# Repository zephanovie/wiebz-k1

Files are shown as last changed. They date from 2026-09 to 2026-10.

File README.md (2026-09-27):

# WIEBZ-K1
The Beginning of a new brand...WIEBZ (Willed Into Existence By Zephan).....its a 60% keyboard with a cool design (i hope)
it uses a raspberry pi pico as the MCU, the switches would be hot swappable. it has a daisy chain of SK6812 mini-e leds that would be both bottom mounted for the per key led and top mounted that would serve as the ambient lights around three corners of the keyboard...and it would be running the qmk firmware. The PCB was designed in KiCad, the case in Fusion 

# Features <br><br>
- Rp2040 controller
- per-key led
- a 60% layout
- under glow lights
- qmk firmware

# BOM

| **Item** | **Qty** | **Price (₦)** | **Price($)** | **Source** |
|---|---|---|---|---|
| PCB | 5 | 48,964.14 | 36.87 (W Shipping) | JLCPCB |
| Raspberry Pi Pico W | 1 | 23,000 | 17.32 | https://hub360.cc/shop/0408-raspberry-pi-pico-w-rp2040-type-c-dual-core-microcontroller-development-board-12216 |
| Kailh Hotswappable MX Sockets | 70 | 8,237 | 6.2 | https://www.aliexpress.com/item/1005012011087592.html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 |
| MX Mechanical Switches | 70 (10*7) | 22,967.57 (W Shipping) | 17.29 | https://www.aliexpress.com/item/1005003206504286.html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 |
| 1N4148 THT Diodes | 100 | 2,207 | 1.66 | https://www.aliexpress.com/item/4001126137167.html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 |
| Stabilizers | 5 | 14,321 | 10.78 | https://www.aliexpress.com/item/4001143514438.html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 |
| SK6812 MINI-E leds | 100 | 5,224 | 3.93 | https://www.aliexpress.com/item/1005007863635868.html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 |
| Transparent PETG | 250g | 25,099 | 18.9 | https://www.aliexpress.com/item/1005012249653635.html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 |
| Matte Black Petg | 1kg | 65,586 | 49.39 | https://www.aliexpress.com/item/1005010748782693.html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 |
| Screws | 0 | 0 | 0 | Self-Covered |
| Heat Inserts | 0 | 0 | 0 | Self-Covered |
| Key Caps | 133 keys  | 19,885 | 14.97 | https://www.aliexpress.com/item/1005009592262575.html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 |
| TOTAL | | 212,523.14 | 140.44 | 

# Images
## Schematics
#### Keyboard Matrix


#### LED Chain


#### MCU


## PCB
#### PCB Design


#### PCB 3D Render



## Case
#### Plate
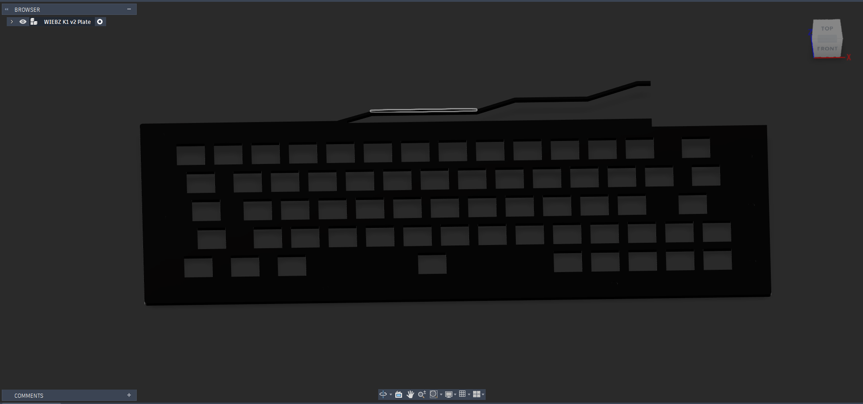
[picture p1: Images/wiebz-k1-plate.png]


#### Base
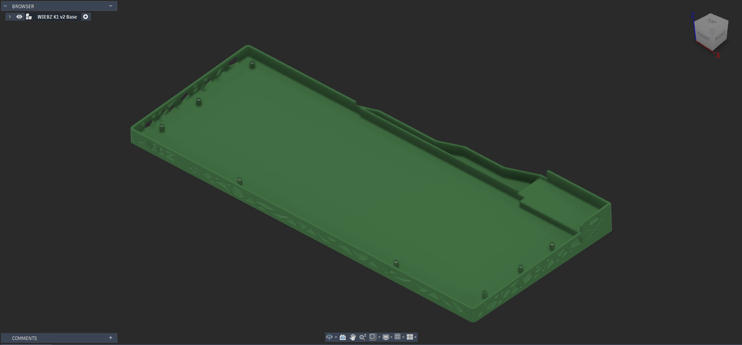
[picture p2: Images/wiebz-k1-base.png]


### MCU Cover
 (to be glue to the plate after printing)
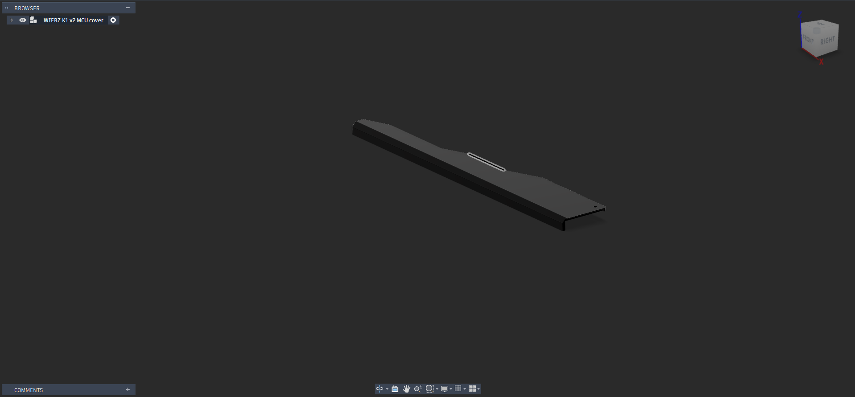
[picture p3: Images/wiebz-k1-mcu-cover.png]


#### Full Case
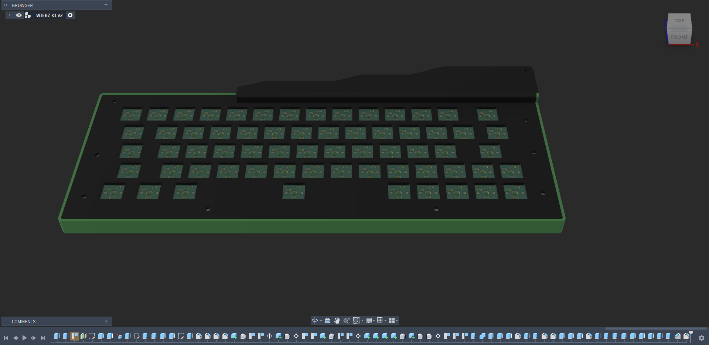
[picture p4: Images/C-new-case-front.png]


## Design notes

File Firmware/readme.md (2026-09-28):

# wiebz_k1

wiebz_k1

*A short description of the keyboard/project*

* Keyboard Maintainer: [Zephan Ovie-Ufuoma](https://github.com/oviezephan)
* Hardware Supported: *The PCBs, controllers supported*
* Hardware Availability: *Links to where you can find this hardware*

Make example for this keyboard (after setting up your build environment):

    make wiebz_k1:default

Flashing example for this keyboard:

    make wiebz_k1:default:flash

See the [build environment setup](https://docs.qmk.fm/#/getting_started_build_tools) and the [make instructions](https://docs.qmk.fm/#/getting_started_make_guide) for more information. Brand new to QMK? Start with our [Complete Newbs Guide](https://docs.qmk.fm/#/newbs).

## Bootloader

Enter the bootloader in 3 ways:

* **Bootmagic reset**: Hold down the key at (0,0) in the matrix (usually the top left key or Escape) and plug in the keyboard
* **Physical reset button**: Briefly press the button on the back of the PCB - some may have pads you must short instead
* **Keycode in layout**: Press the key mapped to `QK_BOOT` if it is available

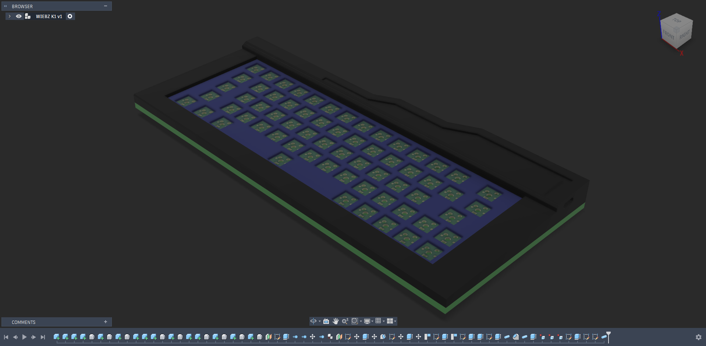
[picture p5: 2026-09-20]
Images/Screenshot 2026-09-20 212914.png

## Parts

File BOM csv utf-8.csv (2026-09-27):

Item | Qty | Price (₦) | Price($) | Source
PCB | 5 | 48,964.14 | 36.87 (W Shipping) | JLCPCB
Raspberry Pi Pico W | 1 | 23,000 | 17.32 | https://hub360.cc/shop/0408-raspberry-pi-pico-w-rp2040-type-c-dual-core-microcontroller-development-board-12216
Kailh Hotswappable MX Sockets | 70 | 8,237 | 6.2 | https://www.aliexpress.com/item/1005012011087592.html?curPageLogUid=ZSE8mI1xv3yo
MX Mechanical Switches | 70 (10*7) | 22,967.57 (W Shipping) | 17.29 | https://www.aliexpress.com/item/1005003206504286.html?curPageLogUid=cNFM0hmjKg5j
1N4148 THT Diodes | 100 | 2,207 | 1.66 | https://www.aliexpress.com/item/4001126137167.html?curPageLogUid=Fgjax7A3c4sT
Stabilizers | 5 | 14,321 | 10.78 | https://www.aliexpress.com/item/4001143514438.html?curPageLogUid=hGLGjyTulFV4
SK6812 MINI-E leds | 100 | 5,224 | 3.93 | https://www.aliexpress.com/item/1005007863635868.html?curPageLogUid=zBx0bm7r2RNj
Transparent PETG | 250g | 25,099 | 18.9 | https://www.aliexpress.com/item/1005012249653635.html?curPageLogUid=4ECKxfp5A1b7
Matte Black Petg | 1kg | 65,586 | 49.39 | https://www.aliexpress.com/item/1005010748782693.html?curPageLogUid=UkhFswVuA9qj
Screws | 0 | 0 | 0 | Self-Covered
Heat Inserts | 0 | 0 | 0 | Self-Covered
Key Caps | 133 keys | 19,885 | 14.97 | https://www.aliexpress.com/item/1005009592262575.html?curPageLogUid=Qs7ffMCvOio6
TOTAL |  | 212,523.14 | 140.44

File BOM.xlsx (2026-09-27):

Item | Qty | Price (₦) | Price($) | Source
PCB | 5 | 48964.14 | 36.87 (W Shipping) | JLCPCB
Raspberry Pi Pico W | 1 | 23000 | 17.32 | https://hub360.cc/shop/0408-raspberry-pi-pico-w-rp2040-type-c-dual-core-microcontroller-development-board-12216
Kailh Hotswappable MX Sockets | 70 | 8237 | 6.2 | https://www.aliexpress.com/item/1005012011087592.html?curPageLogUid=ZSE8mI1xv3yo
MX Mechanical Switches | 70 (10*7) | 22,967.57 (W Shipping) | 17.29 | https://www.aliexpress.com/item/1005003206504286.html?curPageLogUid=cNFM0hmjKg5j
1N4148 THT Diodes | 100 | 2207 | 1.66 | https://www.aliexpress.com/item/4001126137167.html?curPageLogUid=Fgjax7A3c4sT
Stabilizers | 5 | 14321 | 10.78 | https://www.aliexpress.com/item/4001143514438.html?curPageLogUid=hGLGjyTulFV4
SK6812 MINI-E leds | 100 | 5224 | 3.93 | https://www.aliexpress.com/item/1005007863635868.html?curPageLogUid=zBx0bm7r2RNj
Transparent PETG | 250g | 25099 | 18.9 | https://www.aliexpress.com/item/1005012249653635.html?curPageLogUid=4ECKxfp5A1b7
Matte Black Petg | 1kg | 65586 | 49.39 | https://www.aliexpress.com/item/1005010748782693.html?curPageLogUid=UkhFswVuA9qj
Screws | 0 | 0 | 0 | Self-Covered
Heat Inserts | 0 | 0 | 0 | Self-Covered
Key Caps | 133 keys | 19885 | 14.97 | https://www.aliexpress.com/item/1005009592262575.html?curPageLogUid=Qs7ffMCvOio6
TOTAL |  | 212523.14 | 140.44

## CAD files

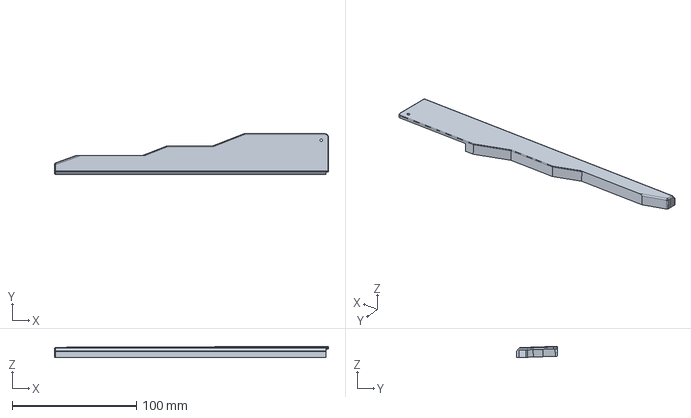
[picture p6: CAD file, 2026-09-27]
Case/WIEBZ K1 v2 MCU cover.step
220.8 x 33.2 x 9.13 mm

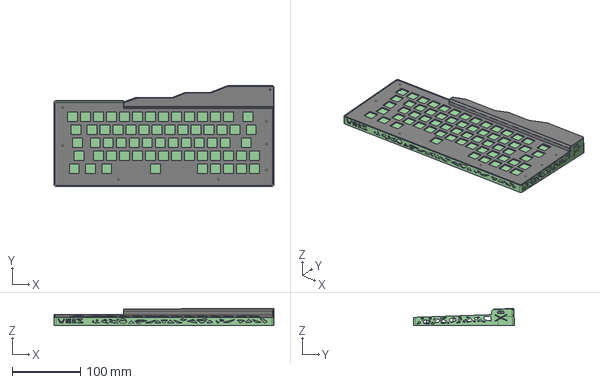
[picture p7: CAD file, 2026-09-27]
Case/WIEBZ K1 v2.step
322.8 x 148.3 x 25.1 mm

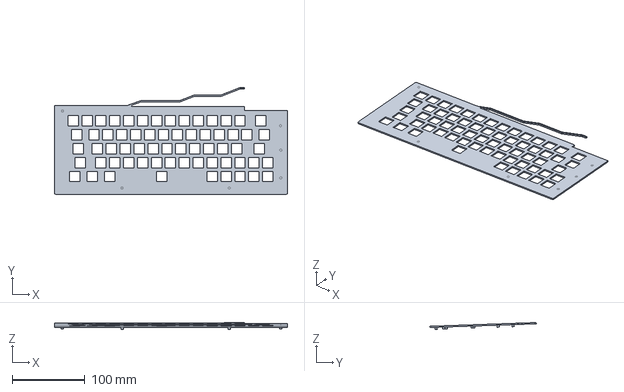
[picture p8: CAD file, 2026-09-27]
Case/WIEBZ K1 v2 Plate.step
319.2 x 146.0 x 9.50 mm

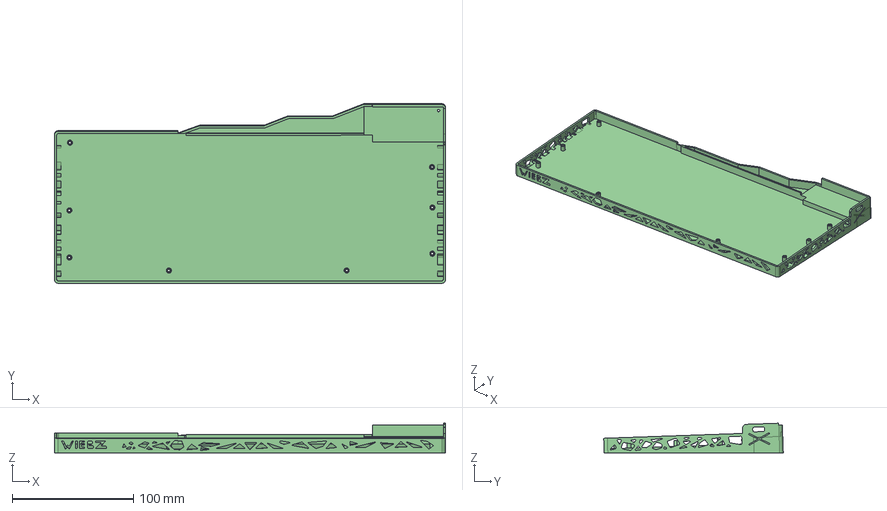
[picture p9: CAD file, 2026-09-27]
Case/WIEBZ K1 v2 Base.step
322.8 x 148.3 x 24.4 mm

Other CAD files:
Case/WIEBZ K1 v2 Plate.f3d

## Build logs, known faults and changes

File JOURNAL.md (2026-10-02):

# August 31 2026: Designed the PCB Schematics
So today i officially started my project (i hope i finish it before the deadline💀💀)…so i started with the pcb schematics ….i didnt finish it today so ill try to do that tommorow (or some time….[im very busy]
(theres a duplicate...i cant find a way to delete the first)

https://lapse.hackclub.com/timelapse/xmWDyl86ip6x
Unfinished PCB

**Total time spent: ~44m**

# September 2nd, 2026: Finished the PCB schematics
i finish the schematics of the keyboard today...connected all the rows and columns... so its remaining the pcb then the case

https://lapse.hackclub.com/timelapse/xmNnxxmWwMwB



**Total time spent: 40m**

# September 3rd, 2026: Added SK6812 Mini-E leds and assigned footprints
wow...i completely forgot im supposed to add leds to the pcb...wow they are a lot and all to be hand soldered...so i did a long hard research onn the sk6812 led datasheets and the rest and found out that the ki cad version was mirrored the other way....so i mirrored it back. Also while assiging footprint i had to search for the big keys size for the stabilizers (Tab, caps, space and the rest)...it said that tab key was 1.5u but i thought it was 2u so i just cotinued like that and yh the spacebar remained the same at 6.25u...so now for the second time....unto the pcb

https://lapse.hackclub.com/timelapse/MGrQsyEzgCeG
https://lapse.hackclub.com/timelapse/5Gh8OEQm45-5




**Total time spent: ~43m**

# September 2nd, 2026: Decided to Make it Hot Swappable
i literally just found out today that its possible to hot swap the actual switches themselves....i wanted to add it to my keyboard so i tried doing some research on it (suprised it took this long)...and most of what i was seeing wasn't helpful....so i had to do it 😔😔...i used AI to help me explain the whole hotswappable switchs and also south facing switches and led placements  and so i went with the kailh mx hot swap circuits...i found the foot prints from another github repo (https://github.com/daprice/keyswitches.pretty)...



**Total time spent: ~1h**

# September 4th, 2026: Finally started the PCB
so i started the pcb design today and boy oh boy i had ALOT of issues...i had to reassign the footprints first was for all the switches to the kailh hot swappable socket...then also resized the big keys(shift, caps and tabs keys). i made a mistake mirroring the sk6812 mini-e led.....yes the kicad one was correct as the led would be mounted on the back of the PCB...so when you flip it (putting it on the bottom of the pcb the pads align)...that was just for the footprints....the main issue that i had her was that the switch footprint just never aligned with each other.....i tried all i colud from changing grid size to changing grid origin and it still wound't align sooo to fix this i decided to use KLE(Keyboard layout editor)...and import it from there....so i had to make the exact layout in KLE...and lowk this help me find another problem....the first 3 bottom row keys weren't 1u but 1.25u and also one random key (\|) was also different at 1.5u....in sure this problem would have had me stressing in the future when doing the pcb...so i guess i dodged a bullet....and to reduce errors and to make it easier later i had to rename the schematics to their respective keys i have'nt changed those keys yet or lay out the pcb ...that would be in the next log(hopefully)

https://lapse.hackclub.com/timelapse/vp1ObMSd3BW9



**Total time spent: ~1h 15m**

# September 6th, 2026: Arranged the Switches, diodes and leds
yh...so the idea of using kle worked pretty well...tho i had to rearrange the diodes cuz they were placed wrongly....and i corrected the sizes of the swithces and stablizers and placed it well on the pcb...also i placed the sk6812 mine e leds individually on the pcb too directly under the swithces...i have'nt routed the pcb yet cuz i ran into a MAJOR brick wall.....the mcu wont fit the pcb design....look like it time to deviate from the refrence...i had to brainstorm on where the mcu would go that would still make the board aesthetically pleasing....after much time thinking....i think ive found a solution (not tested yet)...the mcu could go in the top right horizontally and the extra space i could play it of as a phone holder or sum...ill figure out what to do with the extra space later (prolly when im doing the case)  

https://lapse.hackclub.com/timelapse/-9cZl4bM1H6e




**Total time spent: 1h 23m**

# September 7th, 2026: Finally finished the pcb...bruhh!!!!
yh so today i finnaly finished the pcb design....i didnt follow the refrence for this pcb design (for obviouse reasons).... bro 4h straight aint no joke...but i finnaly did it...i think that the only problem i encountered...was that placing the leds in ascending order was a wrong choice....so i placed it in descending order for easier routing....yh a lot of things but i guess i finished it...now its too move on to the case...anyways here are some pictures

https://lapse.hackclub.com/timelapse/NePFcp5Lkb3h



**Total time spent: 4h 37m**

# September 8th, 2026: Finished troubleshooting the pcb
so i really thought this part would be a work in the park and prolly take like 5mins...so i didnt bother recording in laspe...(it wasnt....). so to start, i first had to do a copper filled zone and connect it to ground which seemed pretty simple...but nah they where ALOT of islands (100+ unconnected items) so i had to individually connect the islands together as there were a lot of componets on the islands...and then the led footprint had a little clearance so i had to edit that since i kept getting errors... and i added some graphics too on the silkscreen layer and yh....i got a lot of warning (483+)...but they were mostly just silkscreeen clearance and it being clipped by other stuffs...so i just ignored them ...and so the main errors i got from drc that had to be resolved were just the unconnected items (turns out i missed a diode to the row ) and the clearance issuse between ALL my leds and the edge cuts....




**Total time spent: ~1h**

# September 9th, 2026: Started the keyboard plate
yh so basically i started the key board plate today...its not complete yet as there are still some unknowns and i have added the stablizers cut out yet....

https://lapse.hackclub.com/timelapse/NlJnQ3O369vW


**Total time spent: 1h 22m**

# September 18th, 2026: Designed the case
well ive been busy for a while and i couldnt continue the project but we are back now.....so yh i switched.....imma build my own keyboard...i call it wiebz-k1...so i started the case...i did the front case and the back case and fitted everything together.....my fusion kept crashing over and over again which go really annoying....well i cant really blame it, i was using about 97% of ram sooo...anyways whats remaning is just to add the screw holes to the back and front case and ill be done with that

https://lapse.hackclub.com/timelapse/3YsnarXC5Usc


**Total time spent: 3h 25m**

# September 20th, 2026: Redesigned the case
so after looking at the first case design...i felt it was kinda bad and bulky for no reason....so today i decided to redesing the case.....completely scraping the front case and only leaving the plate and bottom case....the i dea was to get that floating keys stuff...and also that will make the whole thing more compact

https://lapse.hackclub.com/timelapse/7F3kh3Tarp9o
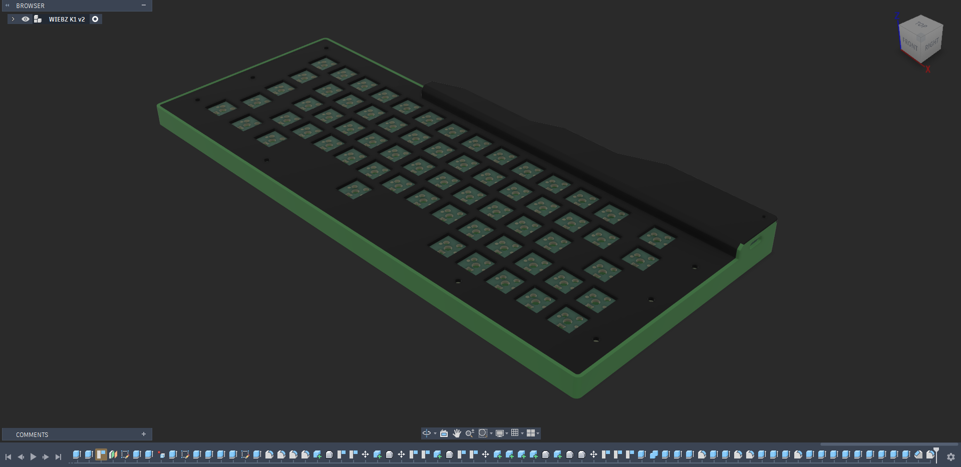
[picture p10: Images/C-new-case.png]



**Total time spent: 2h 32m**

# September 21st, 2026: Worked on the firmware
so yh i just basically did the firmware today... this is just a bare minimun of the firmware....just the normal key funtions for now...i havent added the leds yet... i plan to do that during the build process so i can have a visual on what i am doing
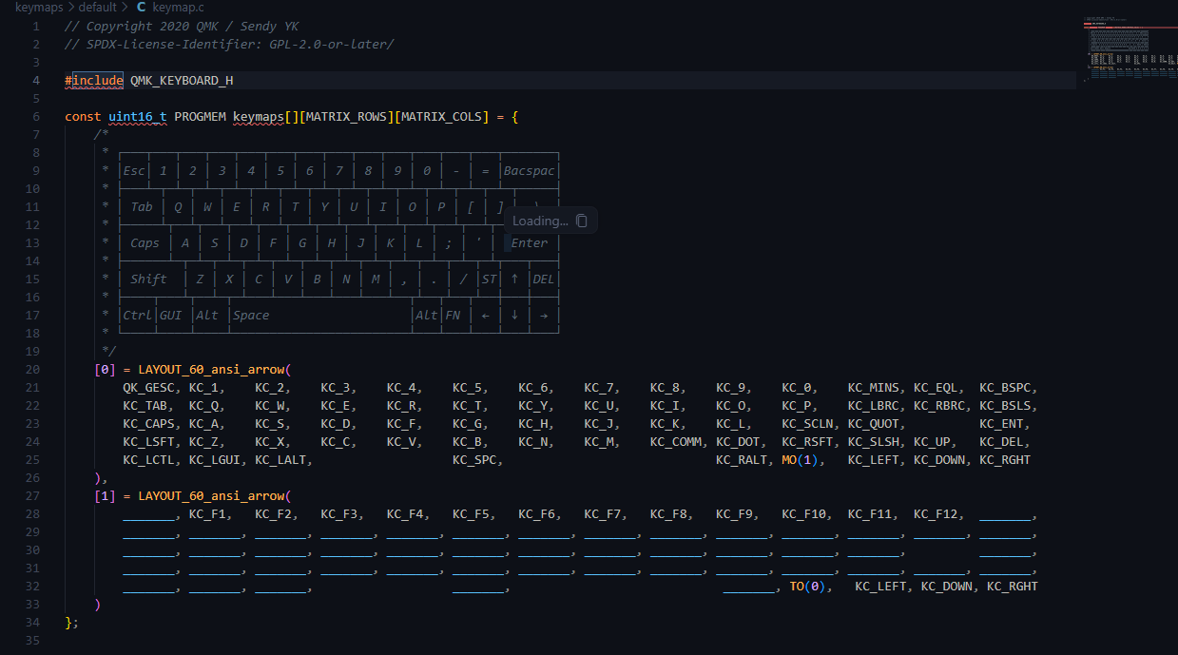
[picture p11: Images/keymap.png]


**Total time spent: ~2h 12m**

# September 22nd, 2026: Case Leds Cutouts
so i added cutouts for the ambient or underglow leds and i wanted to add some contrast to the design....but i know realize its ass...so il have to redesign the cutouts...this time ill use more uniform shapes

https://lapse.hackclub.com/timelapse/n3s-YiddK0XM
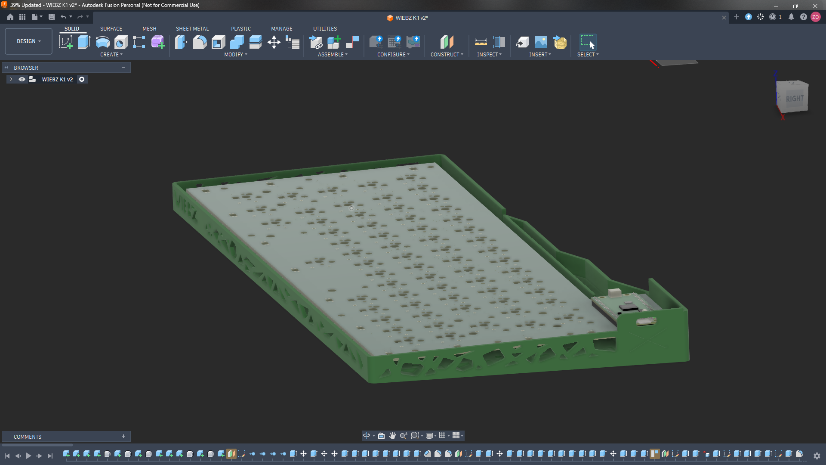
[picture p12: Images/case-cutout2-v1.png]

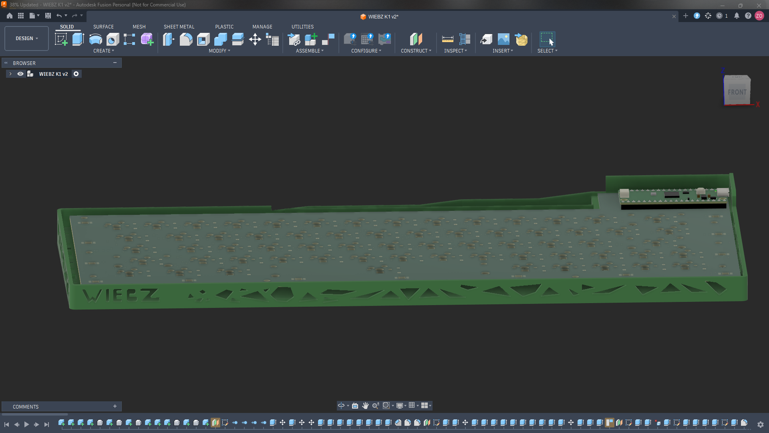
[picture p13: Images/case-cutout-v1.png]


**Total time spent: 2h 2m**

# September 26th, 2026: Finally and Totally Finished with the Case
so i finished adding my screw supports in the case...both the base and the plate...i can just hope the design would work in real life....the case is too big for my 3d printer so ill have to split it but that can come later...and i also added some extra silkscreen on my pcb...this took about 10mins but i didnt record the process

https://lapse.hackclub.com/timelapse/7XiGXEylNQqh
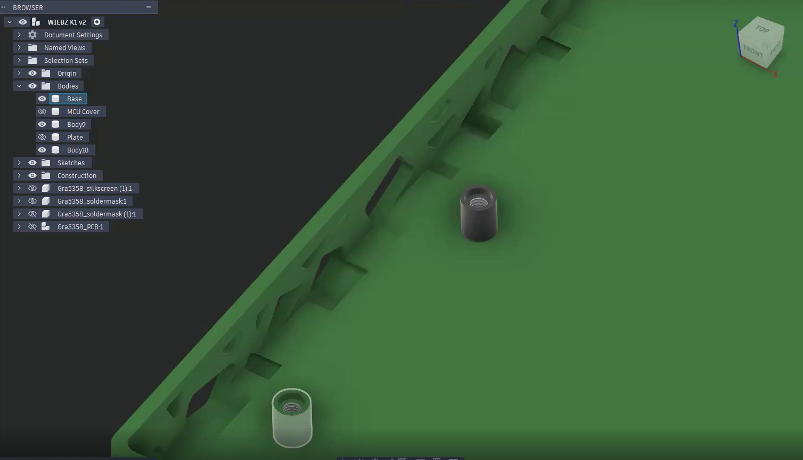
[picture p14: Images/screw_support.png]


**Total time spent: ~46m**

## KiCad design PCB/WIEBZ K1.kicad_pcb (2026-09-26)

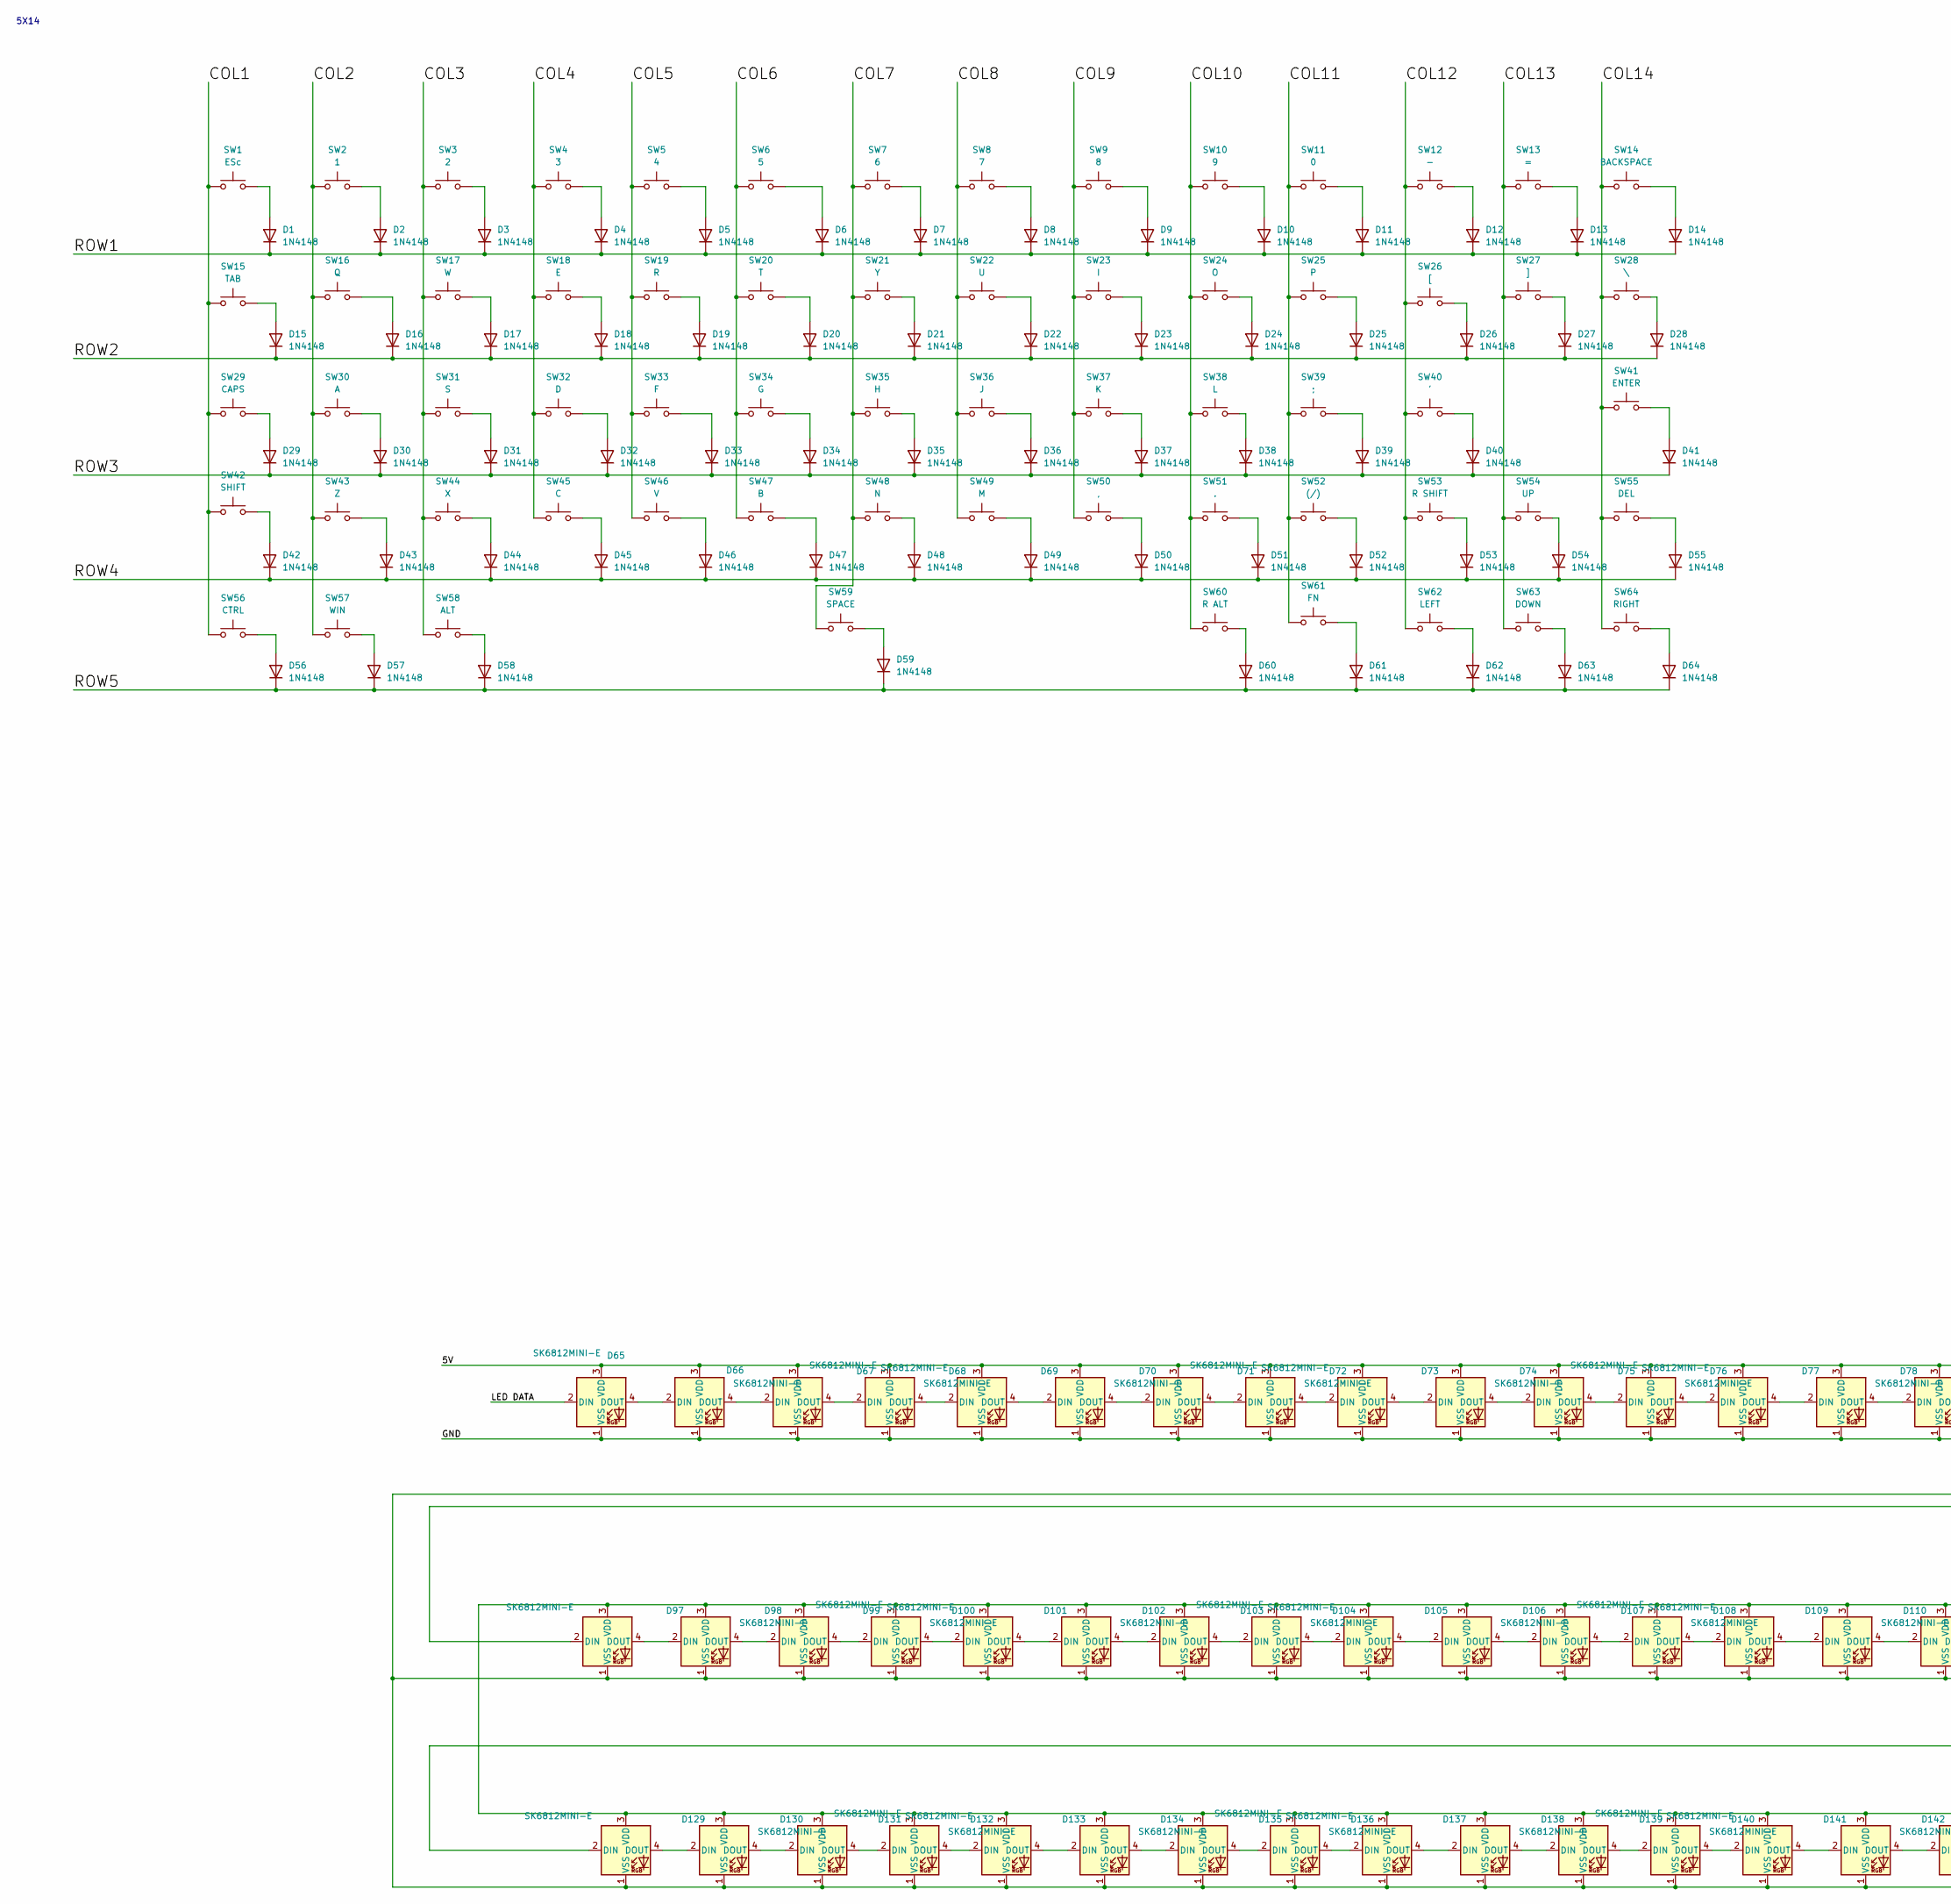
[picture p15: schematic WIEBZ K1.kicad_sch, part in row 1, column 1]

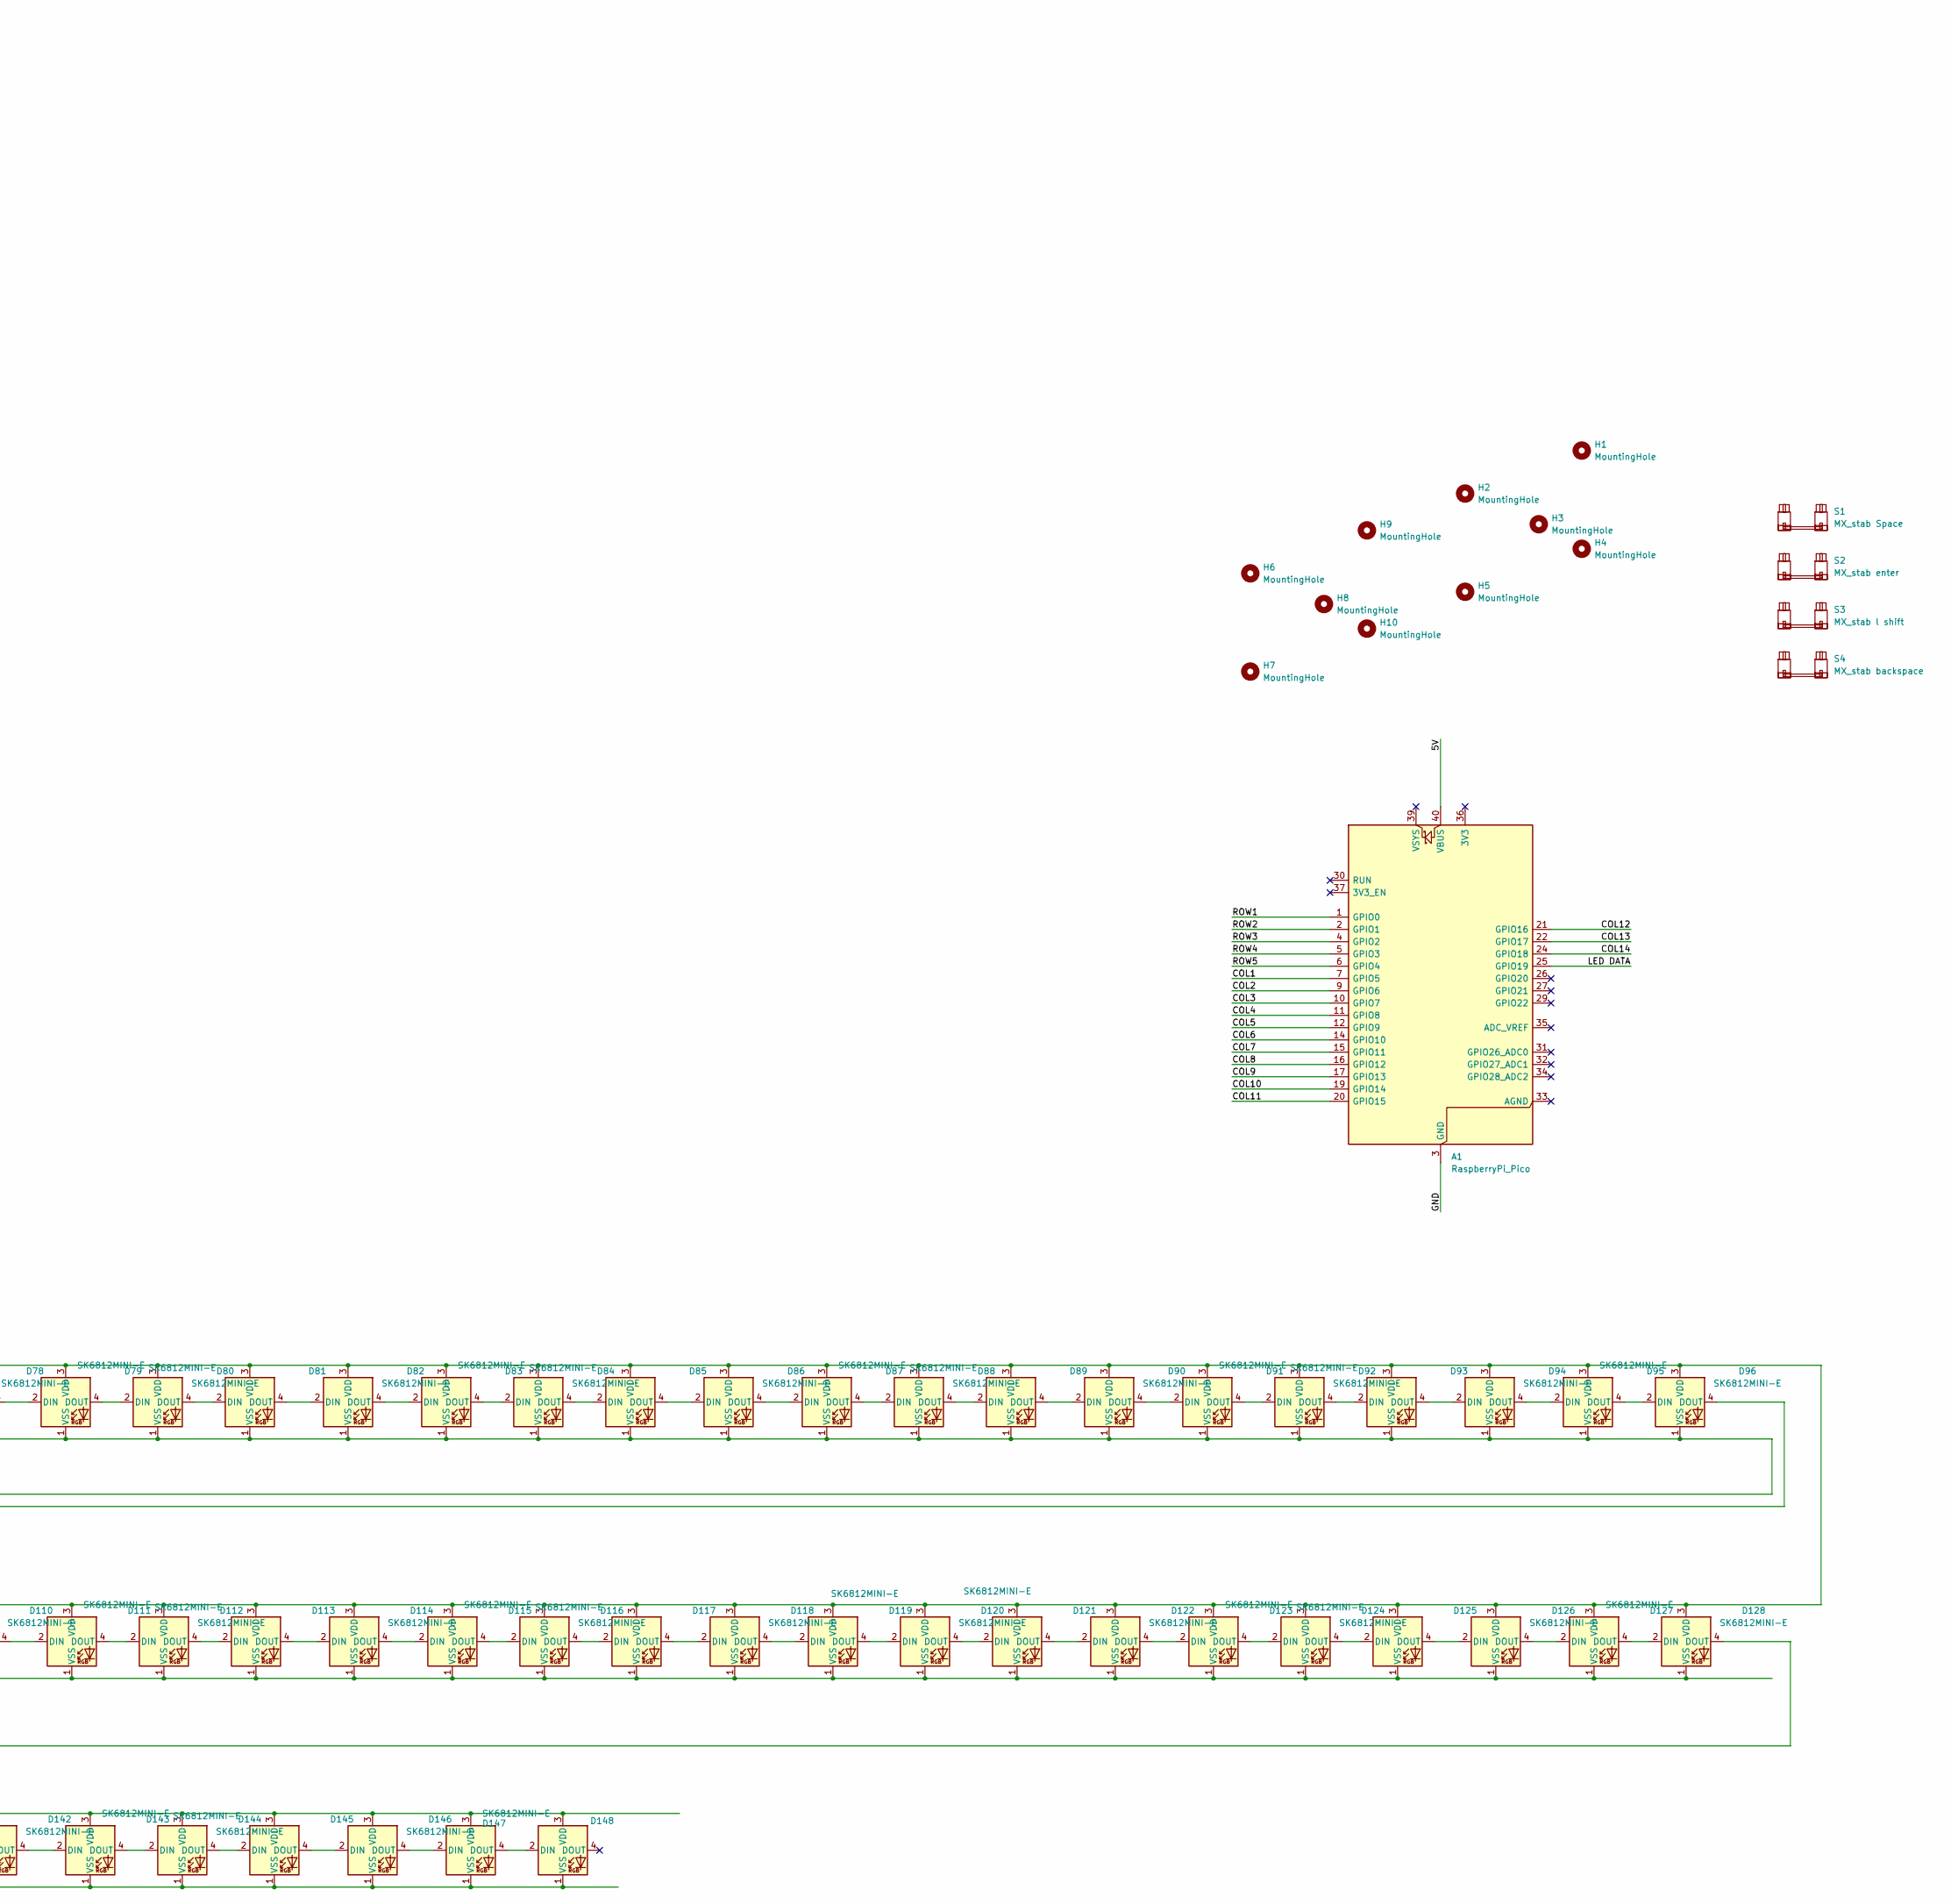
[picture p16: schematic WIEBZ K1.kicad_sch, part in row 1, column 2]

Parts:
A1: RaspberryPi_Pico; RaspberryPi_Pico_Common_THT
D1, D2, D3, D4, D5, D6, D7, D8, D9, D10, D11, D12, D13, D14, D15, D16, D17, D18, D19, D20, D21, D22, D23, D24, D25, D26, D27, D28, D29, D30, D31, D32, D33, D34, D35, D36, D37, D38, D39, D40, D41, D42, D43, D44, D45, D46, D47, D48, D49, D50, D51, D52, D53, D54, D55, D56, D57, D58, D59, D60, D61, D62, D63, D64: 1N4148; D_DO-35_SOD27_P7.62mm_Horizontal
D65, D66, D67, D68, D69, D70, D71, D72, D73, D74, D75, D76, D77, D78, D79, D80, D81, D82, D83, D84, D85, D86, D87, D88, D89, D90, D91, D92, D93, D94, D95, D96, D97, D98, D99, D100, D101, D102, D103, D104, D105, D106, D107, D108, D109, D110, D111, D112, D113, D114, D115, D116, D117, D118, D119, D120, D121, D122, D123, D124, D125, D126, D127, D128, D129, D130, D131, D132, D133, D134, D135, D136, D137, D138, D139, D140, D141, D142, D143, D144, D145, D146, D147, D148: SK6812MINI-E; LED_SK6812MINI-E_3.2x2.8mm_P1.5mm_ReverseMount
H1, H2, H3, H4, H5, H6, H7, H8, H9, H10: MountingHole; MountingHole_3.2mm_M3
S1: MX_stab Space; STAB_MX_6.25u
S2: MX_stab enter; STAB_MX_2.25u
S3: MX_stab l shift; STAB_MX_2u
S4: MX_stab backspace; STAB_MX_2u
SW1: ESc; SW_Hotswap_Kailh_MX_1.00u_No_silk
SW2: 1; SW_Hotswap_Kailh_MX_1.00u_No_silk
SW3: 2; SW_Hotswap_Kailh_MX_1.00u_No_silk
SW4: 3; SW_Hotswap_Kailh_MX_1.00u_No_silk
SW5: 4; SW_Hotswap_Kailh_MX_1.00u_No_silk
SW6: 5; SW_Hotswap_Kailh_MX_1.00u_No_silk
SW7: 6; SW_Hotswap_Kailh_MX_1.00u_No_silk
SW8: 7; SW_Hotswap_Kailh_MX_1.00u_No_silk
SW9: 8; SW_Hotswap_Kailh_MX_1.00u_No_silk
SW10: 9; SW_Hotswap_Kailh_MX_1.00u_No_silk
SW11: 0; SW_Hotswap_Kailh_MX_1.00u_No_silk
SW12: -; SW_Hotswap_Kailh_MX_1.00u_No_silk
SW13: =; SW_Hotswap_Kailh_MX_1.00u_No_silk
SW14: BACKSPACE; SW_Hotswap_Kailh_MX_1.00u_No_silk
SW15: TAB; SW_Hotswap_Kailh_MX_1.00u_No_silk
SW16: Q; SW_Hotswap_Kailh_MX_1.00u_No_silk
SW17: W; SW_Hotswap_Kailh_MX_1.00u_No_silk
SW18: E; SW_Hotswap_Kailh_MX_1.00u_No_silk
SW19: R; SW_Hotswap_Kailh_MX_1.00u_No_silk
SW20: T; SW_Hotswap_Kailh_MX_1.00u_No_silk
SW21: Y; SW_Hotswap_Kailh_MX_1.00u_No_silk
SW22: U; SW_Hotswap_Kailh_MX_1.00u_No_silk
SW23: I; SW_Hotswap_Kailh_MX_1.00u_No_silk
SW24: O; SW_Hotswap_Kailh_MX_1.00u_No_silk
SW25: P; SW_Hotswap_Kailh_MX_1.00u_No_silk
SW26: [; SW_Hotswap_Kailh_MX_1.00u_No_silk
SW27: ]; SW_Hotswap_Kailh_MX_1.00u_No_silk
SW28: \; SW_Hotswap_Kailh_MX_1.00u_No_silk
SW29: CAPS; SW_Hotswap_Kailh_MX_1.00u_No_silk
SW30: A; SW_Hotswap_Kailh_MX_1.00u_No_silk
SW31: S; SW_Hotswap_Kailh_MX_1.00u_No_silk
SW32: D; SW_Hotswap_Kailh_MX_1.00u_No_silk
SW33: F; SW_Hotswap_Kailh_MX_1.00u_No_silk
SW34: G; SW_Hotswap_Kailh_MX_1.00u_No_silk
SW35: H; SW_Hotswap_Kailh_MX_1.00u_No_silk
SW36: J; SW_Hotswap_Kailh_MX_1.00u_No_silk
SW37: K; SW_Hotswap_Kailh_MX_1.00u_No_silk
SW38: L; SW_Hotswap_Kailh_MX_1.00u_No_silk
SW39: ;; SW_Hotswap_Kailh_MX_1.00u_No_silk
SW40: '; SW_Hotswap_Kailh_MX_1.00u_No_silk
SW41: ENTER; SW_Hotswap_Kailh_MX_1.00u_No_silk
SW42: SHIFT; SW_Hotswap_Kailh_MX_1.00u_No_silk
SW43: Z; SW_Hotswap_Kailh_MX_1.00u_No_silk
SW44: X; SW_Hotswap_Kailh_MX_1.00u_No_silk
SW45: C; SW_Hotswap_Kailh_MX_1.00u_No_silk
SW46: V; SW_Hotswap_Kailh_MX_1.00u_No_silk
SW47: B; SW_Hotswap_Kailh_MX_1.00u_No_silk
SW48: N; SW_Hotswap_Kailh_MX_1.00u_No_silk
SW49: M; SW_Hotswap_Kailh_MX_1.00u_No_silk
SW50: ,; SW_Hotswap_Kailh_MX_1.00u_No_silk
SW51: .; SW_Hotswap_Kailh_MX_1.00u_No_silk
SW52: (/); SW_Hotswap_Kailh_MX_1.00u_No_silk
SW53: R SHIFT; SW_Hotswap_Kailh_MX_1.00u_No_silk
SW54: UP; SW_Hotswap_Kailh_MX_1.00u_No_silk
SW55: DEL; SW_Hotswap_Kailh_MX_1.00u_No_silk
SW56: CTRL; SW_Hotswap_Kailh_MX_1.00u_No_silk
SW57: WIN; SW_Hotswap_Kailh_MX_1.00u_No_silk
SW58: ALT; SW_Hotswap_Kailh_MX_1.00u_No_silk
SW59: SPACE; SW_Hotswap_Kailh_MX_1.00u_No_silk
SW60: R ALT; SW_Hotswap_Kailh_MX_1.00u_No_silk
SW61: FN; SW_Hotswap_Kailh_MX_1.00u_No_silk
SW62: LEFT; SW_Hotswap_Kailh_MX_1.00u_No_silk
SW63: DOWN; SW_Hotswap_Kailh_MX_1.00u_No_silk
SW64: RIGHT; SW_Hotswap_Kailh_MX_1.00u_No_silk

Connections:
/5V: A1.40 (VBUS), D65.3 (VDD), D66.3 (VDD), D67.3 (VDD), D68.3 (VDD), D69.3 (VDD), D70.3 (VDD), D71.3 (VDD), D72.3 (VDD), D73.3 (VDD), D74.3 (VDD), D75.3 (VDD), D76.3 (VDD), D77.3 (VDD), D78.3 (VDD), D79.3 (VDD), D80.3 (VDD), D81.3 (VDD), D82.3 (VDD), D83.3 (VDD), D84.3 (VDD), D85.3 (VDD), D86.3 (VDD), D87.3 (VDD), D88.3 (VDD), D89.3 (VDD), D90.3 (VDD), D91.3 (VDD), D92.3 (VDD), D93.3 (VDD), D94.3 (VDD), D95.3 (VDD), D96.3 (VDD), D97.3 (VDD), D98.3 (VDD), D99.3 (VDD), D100.3 (VDD), D101.3 (VDD), D102.3 (VDD), D103.3 (VDD), D104.3 (VDD), D105.3 (VDD), D106.3 (VDD), D107.3 (VDD), D108.3 (VDD), D109.3 (VDD), D110.3 (VDD), D111.3 (VDD), D112.3 (VDD), D113.3 (VDD), D114.3 (VDD), D115.3 (VDD), D116.3 (VDD), D117.3 (VDD), D118.3 (VDD), D119.3 (VDD), D120.3 (VDD), D121.3 (VDD), D122.3 (VDD), D123.3 (VDD), D124.3 (VDD), D125.3 (VDD), D126.3 (VDD), D127.3 (VDD), D128.3 (VDD), D129.3 (VDD), D130.3 (VDD), D131.3 (VDD), D132.3 (VDD), D133.3 (VDD), D134.3 (VDD), D135.3 (VDD), D136.3 (VDD), D137.3 (VDD), D138.3 (VDD), D139.3 (VDD), D140.3 (VDD), D141.3 (VDD), D142.3 (VDD), D143.3 (VDD), D144.3 (VDD), D145.3 (VDD), D146.3 (VDD), D147.3 (VDD), D148.3 (VDD)
/COL1: A1.7 (GPIO5), SW1.1, SW15.1, SW29.1, SW42.1, SW56.1
/COL2: A1.9 (GPIO6), SW2.1, SW16.1, SW30.1, SW43.1, SW57.1
/COL3: A1.10 (GPIO7), SW3.1, SW17.1, SW31.1, SW44.1, SW58.1
/COL4: A1.11 (GPIO8), SW4.1, SW18.1, SW32.1, SW45.1
/COL5: A1.12 (GPIO9), SW5.1, SW19.1, SW33.1, SW46.1
/COL6: A1.14 (GPIO10), SW6.1, SW20.1, SW34.1, SW47.1
/COL7: A1.15 (GPIO11), SW7.1, SW21.1, SW35.1, SW48.1, SW59.1
/COL8: A1.16 (GPIO12), SW8.1, SW22.1, SW36.1, SW49.1
/COL9: A1.17 (GPIO13), SW9.1, SW23.1, SW37.1, SW50.1
/COL10: A1.19 (GPIO14), SW10.1, SW24.1, SW38.1, SW51.1, SW60.1
/COL11: A1.20 (GPIO15), SW11.1, SW25.1, SW39.1, SW52.1, SW61.1
/COL12: A1.21 (GPIO16), SW12.1, SW26.1, SW40.1, SW53.1, SW62.1
/COL13: A1.22 (GPIO17), SW13.1, SW27.1, SW54.1, SW63.1
/COL14: A1.24 (GPIO18), SW14.1, SW28.1, SW41.1, SW55.1, SW64.1
/GND: A1.3 (GND), A1.8 (GND), A1.13 (GND), A1.18 (GND), A1.23 (GND), A1.28 (GND), A1.38 (GND), D65.1 (VSS), D66.1 (VSS), D67.1 (VSS), D68.1 (VSS), D69.1 (VSS), D70.1 (VSS), D71.1 (VSS), D72.1 (VSS), D73.1 (VSS), D74.1 (VSS), D75.1 (VSS), D76.1 (VSS), D77.1 (VSS), D78.1 (VSS), D79.1 (VSS), D80.1 (VSS), D81.1 (VSS), D82.1 (VSS), D83.1 (VSS), D84.1 (VSS), D85.1 (VSS), D86.1 (VSS), D87.1 (VSS), D88.1 (VSS), D89.1 (VSS), D90.1 (VSS), D91.1 (VSS), D92.1 (VSS), D93.1 (VSS), D94.1 (VSS), D95.1 (VSS), D96.1 (VSS), D97.1 (VSS), D98.1 (VSS), D99.1 (VSS), D100.1 (VSS), D101.1 (VSS), D102.1 (VSS), D103.1 (VSS), D104.1 (VSS), D105.1 (VSS), D106.1 (VSS), D107.1 (VSS), D108.1 (VSS), D109.1 (VSS), D110.1 (VSS), D111.1 (VSS), D112.1 (VSS), D113.1 (VSS), D114.1 (VSS), D115.1 (VSS), D116.1 (VSS), D117.1 (VSS), D118.1 (VSS), D119.1 (VSS), D120.1 (VSS), D121.1 (VSS), D122.1 (VSS), D123.1 (VSS), D124.1 (VSS), D125.1 (VSS), D126.1 (VSS), D127.1 (VSS), D128.1 (VSS), D129.1 (VSS), D130.1 (VSS), D131.1 (VSS), D132.1 (VSS), D133.1 (VSS), D134.1 (VSS), D135.1 (VSS), D136.1 (VSS), D137.1 (VSS), D138.1 (VSS), D139.1 (VSS), D140.1 (VSS), D141.1 (VSS), D142.1 (VSS), D143.1 (VSS), D144.1 (VSS), D145.1 (VSS), D146.1 (VSS), D147.1 (VSS), D148.1 (VSS)
/LED DATA: A1.25 (GPIO19), D65.2 (DIN)
/ROW1: A1.1 (GPIO0), D1.1 (K), D2.1 (K), D3.1 (K), D4.1 (K), D5.1 (K), D6.1 (K), D7.1 (K), D8.1 (K), D9.1 (K), D10.1 (K), D11.1 (K), D12.1 (K), D13.1 (K), D14.1 (K)
/ROW2: A1.2 (GPIO1), D15.1 (K), D16.1 (K), D17.1 (K), D18.1 (K), D19.1 (K), D20.1 (K), D21.1 (K), D22.1 (K), D23.1 (K), D24.1 (K), D25.1 (K), D26.1 (K), D27.1 (K), D28.1 (K)
/ROW3: A1.4 (GPIO2), D29.1 (K), D30.1 (K), D31.1 (K), D32.1 (K), D33.1 (K), D34.1 (K), D35.1 (K), D36.1 (K), D37.1 (K), D38.1 (K), D39.1 (K), D40.1 (K), D41.1 (K)
/ROW4: A1.5 (GPIO3), D42.1 (K), D43.1 (K), D44.1 (K), D45.1 (K), D46.1 (K), D47.1 (K), D48.1 (K), D49.1 (K), D50.1 (K), D51.1 (K), D52.1 (K), D53.1 (K), D54.1 (K), D55.1 (K)
/ROW5: A1.6 (GPIO4), D56.1 (K), D57.1 (K), D58.1 (K), D59.1 (K), D60.1 (K), D61.1 (K), D62.1 (K), D63.1 (K), D64.1 (K)
unnamed: D1.2 (A), SW1.2
unnamed: D2.2 (A), SW2.2
unnamed: D3.2 (A), SW3.2
unnamed: D4.2 (A), SW4.2
unnamed: D5.2 (A), SW5.2
unnamed: D6.2 (A), SW6.2
unnamed: D7.2 (A), SW7.2
unnamed: D8.2 (A), SW8.2
unnamed: D9.2 (A), SW9.2
unnamed: D10.2 (A), SW10.2
unnamed: D11.2 (A), SW11.2
unnamed: D12.2 (A), SW12.2
unnamed: D13.2 (A), SW13.2
unnamed: D14.2 (A), SW14.2
unnamed: D15.2 (A), SW15.2
unnamed: D16.2 (A), SW16.2
unnamed: D17.2 (A), SW17.2
unnamed: D18.2 (A), SW18.2
unnamed: D19.2 (A), SW19.2
unnamed: D20.2 (A), SW20.2
unnamed: D21.2 (A), SW21.2
unnamed: D22.2 (A), SW22.2
unnamed: D23.2 (A), SW23.2
unnamed: D24.2 (A), SW24.2
unnamed: D25.2 (A), SW25.2
unnamed: D26.2 (A), SW26.2
unnamed: D27.2 (A), SW27.2
unnamed: D28.2 (A), SW28.2
unnamed: D29.2 (A), SW29.2
unnamed: D30.2 (A), SW30.2
unnamed: D31.2 (A), SW31.2
unnamed: D32.2 (A), SW32.2
unnamed: D33.2 (A), SW33.2
unnamed: D34.2 (A), SW34.2
unnamed: D35.2 (A), SW35.2
unnamed: D36.2 (A), SW36.2
unnamed: D37.2 (A), SW37.2
unnamed: D38.2 (A), SW38.2
unnamed: D39.2 (A), SW39.2
unnamed: D40.2 (A), SW40.2
unnamed: D41.2 (A), SW41.2
unnamed: D42.2 (A), SW42.2
unnamed: D43.2 (A), SW43.2
unnamed: D44.2 (A), SW44.2
unnamed: D45.2 (A), SW45.2
unnamed: D46.2 (A), SW46.2
unnamed: D47.2 (A), SW47.2
unnamed: D48.2 (A), SW48.2
unnamed: D49.2 (A), SW49.2
unnamed: D50.2 (A), SW50.2
unnamed: D51.2 (A), SW51.2
unnamed: D52.2 (A), SW52.2
unnamed: D53.2 (A), SW53.2
unnamed: D54.2 (A), SW54.2
unnamed: D55.2 (A), SW55.2
unnamed: D56.2 (A), SW56.2
unnamed: D57.2 (A), SW57.2
unnamed: D58.2 (A), SW58.2
unnamed: D59.2 (A), SW59.2
unnamed: D60.2 (A), SW60.2
unnamed: D61.2 (A), SW61.2
unnamed: D62.2 (A), SW62.2
unnamed: D63.2 (A), SW63.2
unnamed: D64.2 (A), SW64.2
unnamed: D65.4 (DOUT), D66.2 (DIN)
unnamed: D66.4 (DOUT), D67.2 (DIN)
unnamed: D67.4 (DOUT), D68.2 (DIN)
unnamed: D68.4 (DOUT), D69.2 (DIN)
unnamed: D69.4 (DOUT), D70.2 (DIN)
unnamed: D70.4 (DOUT), D71.2 (DIN)
unnamed: D71.4 (DOUT), D72.2 (DIN)
unnamed: D72.4 (DOUT), D73.2 (DIN)
unnamed: D73.4 (DOUT), D74.2 (DIN)
unnamed: D74.4 (DOUT), D75.2 (DIN)
unnamed: D75.4 (DOUT), D76.2 (DIN)
unnamed: D76.4 (DOUT), D77.2 (DIN)
unnamed: D77.4 (DOUT), D78.2 (DIN)
unnamed: D78.4 (DOUT), D79.2 (DIN)
unnamed: D79.4 (DOUT), D80.2 (DIN)
unnamed: D80.4 (DOUT), D81.2 (DIN)
unnamed: D81.4 (DOUT), D82.2 (DIN)
unnamed: D82.4 (DOUT), D83.2 (DIN)
unnamed: D83.4 (DOUT), D84.2 (DIN)
unnamed: D84.4 (DOUT), D85.2 (DIN)
unnamed: D85.4 (DOUT), D86.2 (DIN)
unnamed: D86.4 (DOUT), D87.2 (DIN)
unnamed: D87.4 (DOUT), D88.2 (DIN)
unnamed: D88.4 (DOUT), D89.2 (DIN)
unnamed: D89.4 (DOUT), D90.2 (DIN)
unnamed: D90.4 (DOUT), D91.2 (DIN)
unnamed: D91.4 (DOUT), D92.2 (DIN)
unnamed: D92.4 (DOUT), D93.2 (DIN)
unnamed: D93.4 (DOUT), D94.2 (DIN)
unnamed: D94.4 (DOUT), D95.2 (DIN)
unnamed: D95.4 (DOUT), D96.2 (DIN)
unnamed: D96.4 (DOUT), D97.2 (DIN)
unnamed: D97.4 (DOUT), D98.2 (DIN)
unnamed: D98.4 (DOUT), D99.2 (DIN)
unnamed: D99.4 (DOUT), D100.2 (DIN)
unnamed: D100.4 (DOUT), D101.2 (DIN)
unnamed: D101.4 (DOUT), D102.2 (DIN)
unnamed: D102.4 (DOUT), D103.2 (DIN)
unnamed: D103.4 (DOUT), D104.2 (DIN)
unnamed: D104.4 (DOUT), D105.2 (DIN)
unnamed: D105.4 (DOUT), D106.2 (DIN)
unnamed: D106.4 (DOUT), D107.2 (DIN)
unnamed: D107.4 (DOUT), D108.2 (DIN)
unnamed: D108.4 (DOUT), D109.2 (DIN)
unnamed: D109.4 (DOUT), D110.2 (DIN)
unnamed: D110.4 (DOUT), D111.2 (DIN)
unnamed: D111.4 (DOUT), D112.2 (DIN)
unnamed: D112.4 (DOUT), D113.2 (DIN)
unnamed: D113.4 (DOUT), D114.2 (DIN)
unnamed: D114.4 (DOUT), D115.2 (DIN)
unnamed: D115.4 (DOUT), D116.2 (DIN)
unnamed: D116.4 (DOUT), D117.2 (DIN)
unnamed: D117.4 (DOUT), D118.2 (DIN)
unnamed: D118.4 (DOUT), D119.2 (DIN)
unnamed: D119.4 (DOUT), D120.2 (DIN)
unnamed: D120.4 (DOUT), D121.2 (DIN)
unnamed: D121.4 (DOUT), D122.2 (DIN)
unnamed: D122.4 (DOUT), D123.2 (DIN)
unnamed: D123.4 (DOUT), D124.2 (DIN)
unnamed: D124.4 (DOUT), D125.2 (DIN)
unnamed: D125.4 (DOUT), D126.2 (DIN)
unnamed: D126.4 (DOUT), D127.2 (DIN)
unnamed: D127.4 (DOUT), D128.2 (DIN)
unnamed: D128.4 (DOUT), D129.2 (DIN)
unnamed: D129.4 (DOUT), D130.2 (DIN)
unnamed: D130.4 (DOUT), D131.2 (DIN)
unnamed: D131.4 (DOUT), D132.2 (DIN)
unnamed: D132.4 (DOUT), D133.2 (DIN)
unnamed: D133.4 (DOUT), D134.2 (DIN)
unnamed: D134.4 (DOUT), D135.2 (DIN)
unnamed: D135.4 (DOUT), D136.2 (DIN)
unnamed: D136.4 (DOUT), D137.2 (DIN)
unnamed: D137.4 (DOUT), D138.2 (DIN)
unnamed: D138.4 (DOUT), D139.2 (DIN)
unnamed: D139.4 (DOUT), D140.2 (DIN)
unnamed: D140.4 (DOUT), D141.2 (DIN)
unnamed: D141.4 (DOUT), D142.2 (DIN)
unnamed: D142.4 (DOUT), D143.2 (DIN)
unnamed: D143.4 (DOUT), D144.2 (DIN)
unnamed: D144.4 (DOUT), D145.2 (DIN)
unnamed: D145.4 (DOUT), D146.2 (DIN)
unnamed: D146.4 (DOUT), D147.2 (DIN)
unnamed: D147.4 (DOUT), D148.2 (DIN)

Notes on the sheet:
5X14

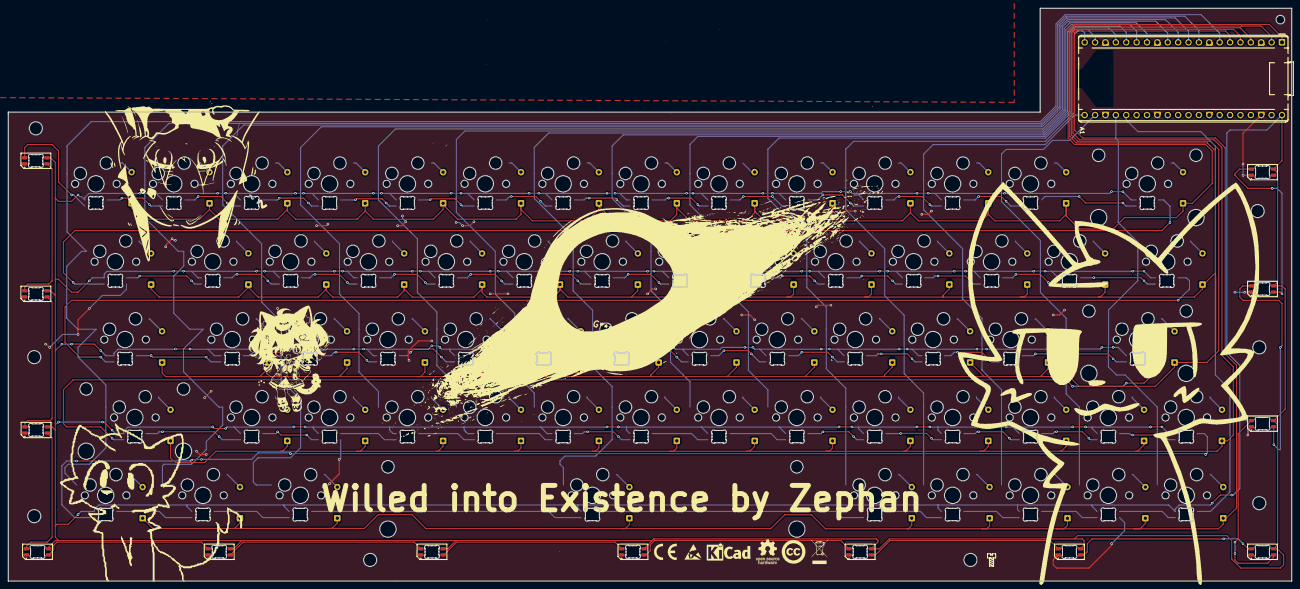
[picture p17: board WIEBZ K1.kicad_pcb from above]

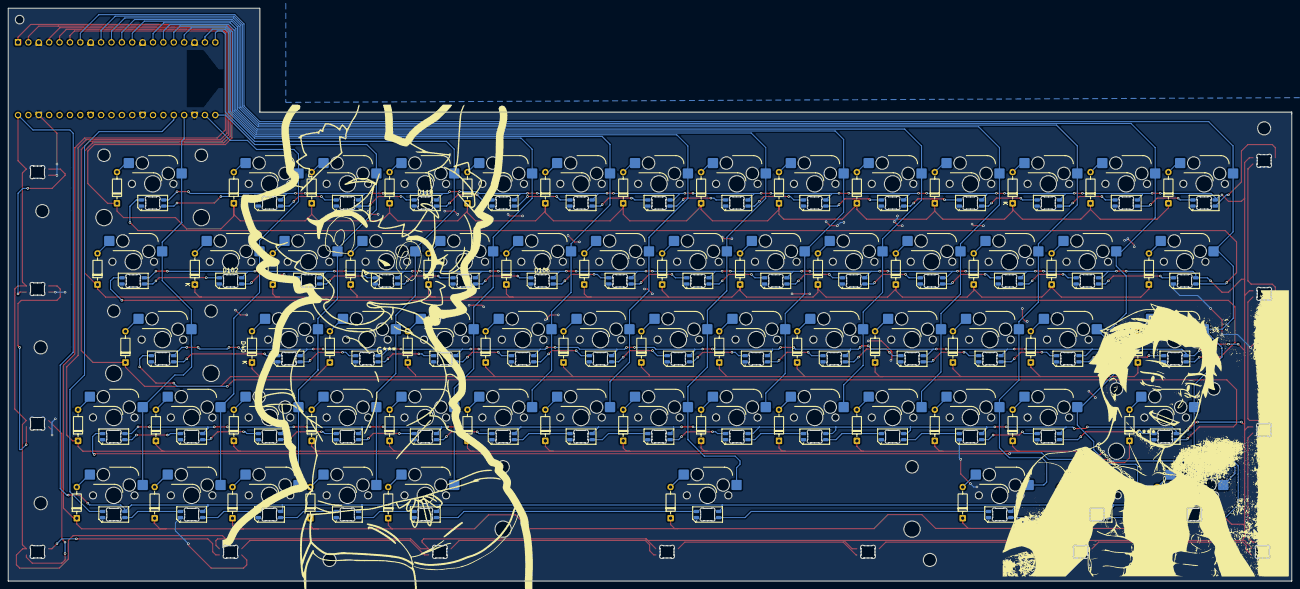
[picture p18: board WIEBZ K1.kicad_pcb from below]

Board: 2 copper layers, 313.9 x 140.1 mm, 218 parts (128 on the bottom side), 162 nets.

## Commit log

2026-09-20 Rename Screenshot 2026-09-20 212853.png to C-new-case.png
2026-09-20 Rename Screenshot 2026-09-20 212914.png to C-old-case.png
2026-09-20 Rename Screenshot 2026-09-20 212944.png to C-new-case-front.png
2026-09-20 Redesign case layout for improved compactness
    Redesigned the case by removing the front and focusing on a more compact design with floating keys.
2026-09-26 Rename Screenshot 2026-09-26 154423.png to case-cutout-v1.png
2026-09-26 Rename Screenshot 2026-09-26 154436.png to case-cutout2-v1.png
2026-09-26 Create Case
2026-09-26 Rename Screenshot 2026-09-26 220106.png to screw_support.png
2026-09-27 Refactor BOM table format in README
    Updated the BOM table format for better readability.
2026-09-27 Rename Screenshot 2026-09-27 233514.png to wiebz-k1-plate.png
2026-09-27 Add note for gluing MCU cover after printing
    Added note about gluing the MCU cover to the plate after printing.
2026-10-07 Rename WIEBZ K1 v2 Plate.f3d to Case/WIEBZ K1 v2 Plate.f3d
    [WIEBZ K1 v2 Plate.f3d]
